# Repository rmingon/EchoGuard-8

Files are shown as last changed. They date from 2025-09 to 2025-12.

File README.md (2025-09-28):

# GPS Fusion Array with STM32F103

This repository contains the full design files, schematics, and firmware for a **GPS Fusion Array**:
a custom PCB with **8 ATGM336H GNSS modules** and an **STM32F103 MCU** that collects data from all receivers,
performs **real-time fusion**, and outputs the combined solution over **SPI**.

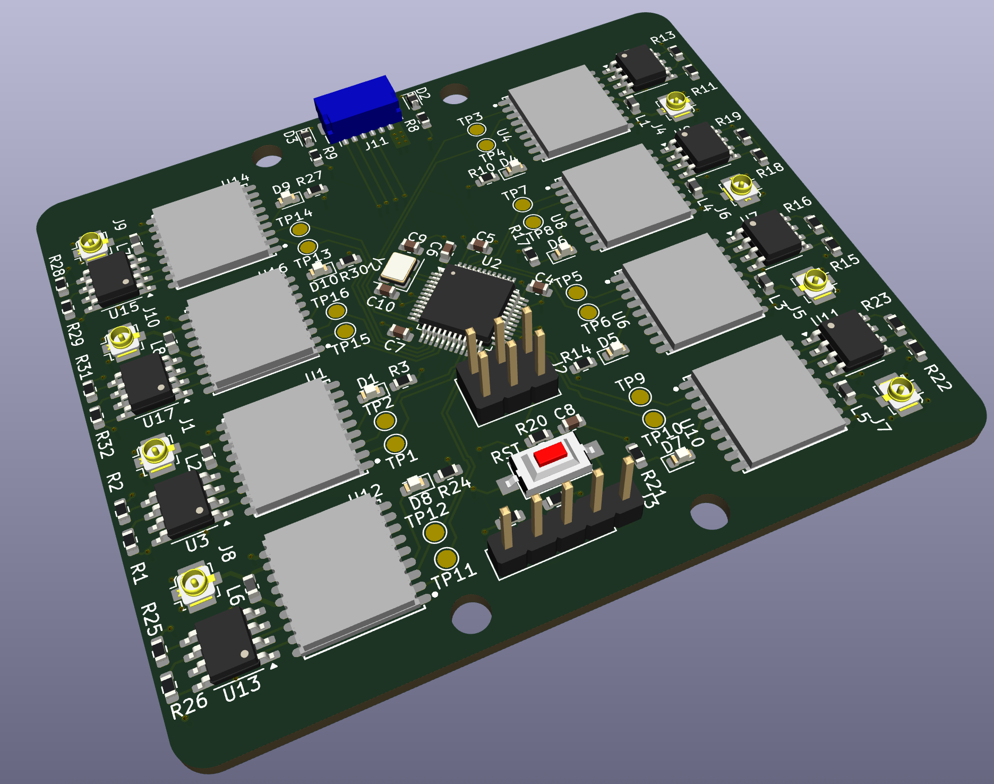
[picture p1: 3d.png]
3d


## Support on falconEdge

[FalconEdge repository](https://github.com/rmingon/Falcon-Edge)

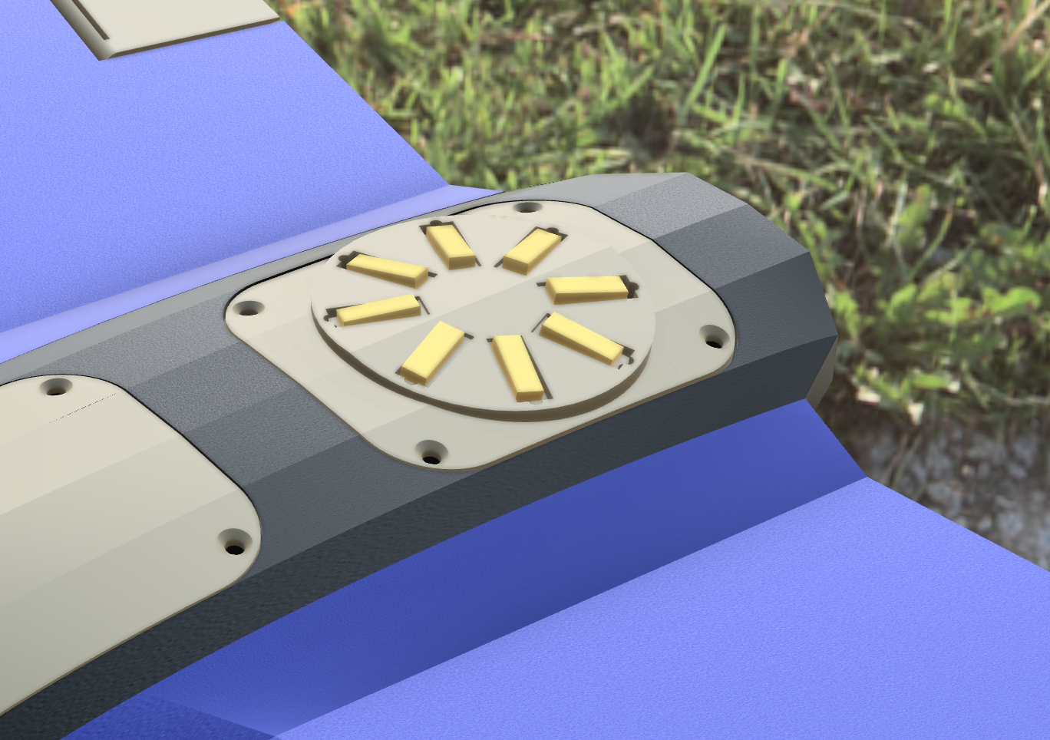
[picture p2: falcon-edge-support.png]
falconEdge_support


---

## Project Overview

| PCB Layout | Schematic | 3D View |
| --- | --- | --- |
| pcb.png | schematic.png | 3d.png  |

---

## Key Features

- **8× ATGM336H GPS modules** for redundant positioning
- **STM32F103** microcontroller for acquisition and fusion
- **SPI output interface** for fast integration with a master controller
- **Per-module power filtering** and **careful ground plane partitioning** to reduce RF interference
- **Compact, mountable PCB** with 3.3 V power input

---

## Why an Array of GPS Modules?

Traditional single-GPS solutions suffer from multipath, interference, and occasional dropouts.
Using 8 GPS modules in parallel offers:

- **Redundancy:** Even if one receiver loses lock, others keep tracking.
- **Noise Reduction:** Position noise is reduced by averaging multiple solutions.
- **Outlier Rejection:** Bad data can be discarded automatically.
- **Improved Accuracy:** Fusion of multiple measurements yields a more stable, reliable solution.

---

## RF & Interference Mitigation

This PCB design includes several techniques to minimize interference and maintain clean GNSS reception:

- **Dedicated RF Ground Plane:** Each GPS module has local ground pour to reduce mutual coupling.
- **Power Filtering:** Each module’s VCC line is decoupled with LC filters for low-noise operation.
- **Symmetric Layout:** GPS modules are evenly distributed to reduce antenna detuning.
- **Isolated Digital Section:** MCU and SPI routing are kept away from RF traces to reduce emissions.

---

## Data Fusion Algorithm

The STM32F103 runs a lightweight fusion algorithm:

- **NMEA Parsing** from all modules
- **Timestamp Synchronization** for simultaneous position updates
- **Weighted Average & Kalman Filtering** using HDOP as weight
- **Fault Detection:** Rejects outliers and maintains smooth position tracking

---

## Firmware

Features:

- **Complete NMEA Parsing** Supports GGA, RMC, GSA, GSV, VTG, and GLL sentences
- **Interrupt Support** Optional interrupt-driven data reception
- **Comprehensive Data** Position, time, satellites, signal quality, movement data
- **Signal Quality Analysis** SNR monitoring and satellite constellation health

---

## ATGM336H Technical Summary

| Parameter | Specification |
| --- | --- |
| Constellations | GPS, BeiDou, GLONASS, QZSS, SBAS |
| Positioning Accuracy | ~2.5 m CEP |
| Cold Start | < 35 s |
| Hot Start | < 1 s |
| Update Rate | Up to 10 Hz |
| Supply Voltage | 2.8 – 4.3 V |
| Interface | UART (NMEA) |
| Tracking Current | ~26 mA |
| Operating Temp | -40 °C to +85 °C |

---

## Hardware Details

- **MCU:** STM32F103C8T6
- **GPS:** 8× ATGM336H modules
- **I/O:** SPI slave output, UARTs for module communication
- **Power:** Single 3.3 V input, on-board filtering
- **Board:** 4-layer PCB, optimized RF layout

---

## Repository Structure

```
/hardware       # KiCad project files, schematics, PCB layout
/firmware       # STM32 source code for GPS fusion and SPI output
/docs           # Project documentation, images, diagrams
```

---

## Getting Started

1. **Assemble the PCB** and mount the GPS modules and STM32.
2. **Flash the firmware** using ST-Link.
3. **Connect SPI** to your master controller (e.g., Raspberry Pi or another STM32).
4. **Power the board** with 3.3 V regulated input.
5. **Start reading fused GPS data** from SPI.

## License

This project is licensed under the **CERN Open Hardware Licence Version 2**. See `LICENSE` file for full terms.

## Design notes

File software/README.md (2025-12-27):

# Software (PlatformIO)

This folder contains a minimal PlatformIO project targeting **STM32F103C8** using **STM32Cube (HAL)** + **FreeRTOS**.

## GNSS UART Pin Map

The hardware connects 8× ATGM336H modules using nets `TX_1..TX_8` / `RX_1..RX_8`:

- GNSS #1: TX=`PB10` (net `TX_1`), RX=`PB11` (net `RX_1`) → `USART3`
- GNSS #2: TX=`PA2` (net `TX_2`), RX=`PA3` (net `RX_2`) → `USART2`
- GNSS #3: TX=`PB6` (net `TX_3`), RX=`PB7` (net `RX_3`) → `USART1` (remapped)
- GNSS #4: TX=`PB8` (net `TX_4`), RX=`PB9` (net `RX_4`)
- GNSS #5: TX=`PB12` (net `TX_5`), RX=`PB13` (net `RX_5`)
- GNSS #6: TX=`PB14` (net `TX_6`), RX=`PB15` (net `RX_6`)
- GNSS #7: TX=`PA4` (net `TX_7`), RX=`PA5` (net `RX_7`)
- GNSS #8: TX=`PA6` (net `TX_8`), RX=`PA7` (net `RX_8`)

Only GNSS modules #1..#3 are on hardware USART pin pairs; the rest need a software UART (or other method) if all
8 modules must be received concurrently.

## SPI Fused Output (J11)

Hardware SPI connector `J11` (JST-SH 1x06):

- Pin 1: `SS` (PB1, active-low)
- Pin 2: `MOSI` (PB5)
- Pin 3: `MISO` (PB4)
- Pin 4: `SCK` (PB3)
- Pin 5: `GND`
- Pin 6: `+3.3V`

Firmware exposes the fused GNSS solution as an `SPI1` slave (remapped to PB3/PB4/PB5). Each `SS` assertion starts
a streamed `SPI_FUSION_PACKET_SIZE`-byte packet on `MISO` (see `include/spi_fusion.h`).

Packet (little-endian, `SPI_FUSION_PACKET_SIZE == 32`):

- `u32 magic` = `0x31464745` (`EGF1`)
- `u32 tick_ms`
- `i32 lat_e7`, `i32 lon_e7`, `i32 alt_cm`
- `u16 avg_hdop_centi`, `u16 max_residual_cm`
- `u8 status`, `u8 used_modules`, `u8 rejected_modules`, `u8 has_fix`
- `u16 crc16_ccitt` (over first 30 bytes)

## Build / Upload

- Install PlatformIO CLI (or use the VS Code PlatformIO extension).
- From `software/`:
  - Build: `pio run`
  - Upload (ST-Link): `pio run -t upload`

`FreeRTOS-Kernel` is pulled via `lib_deps` (requires network access on first build).

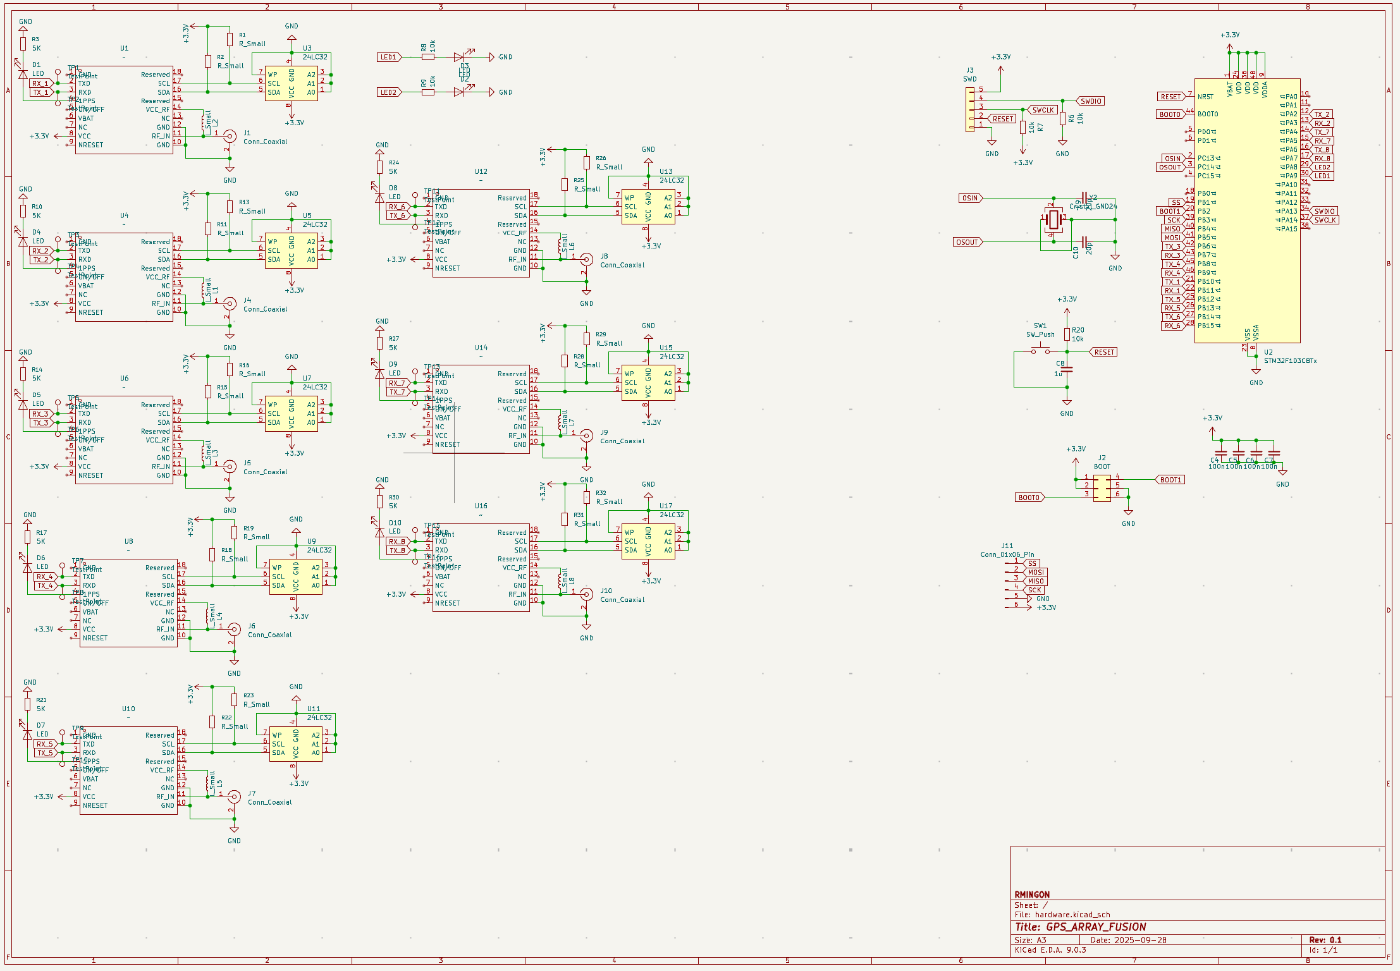
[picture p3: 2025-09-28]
schematic.png

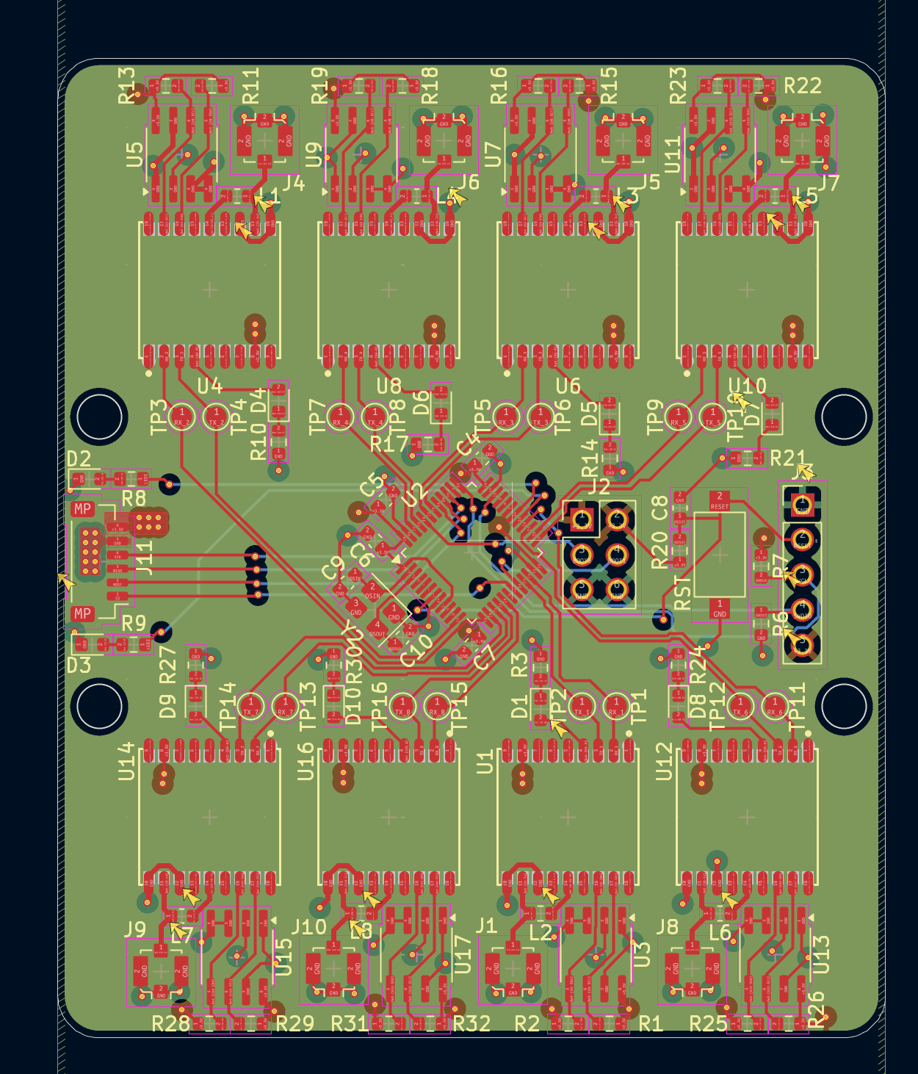
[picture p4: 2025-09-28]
pcb.png

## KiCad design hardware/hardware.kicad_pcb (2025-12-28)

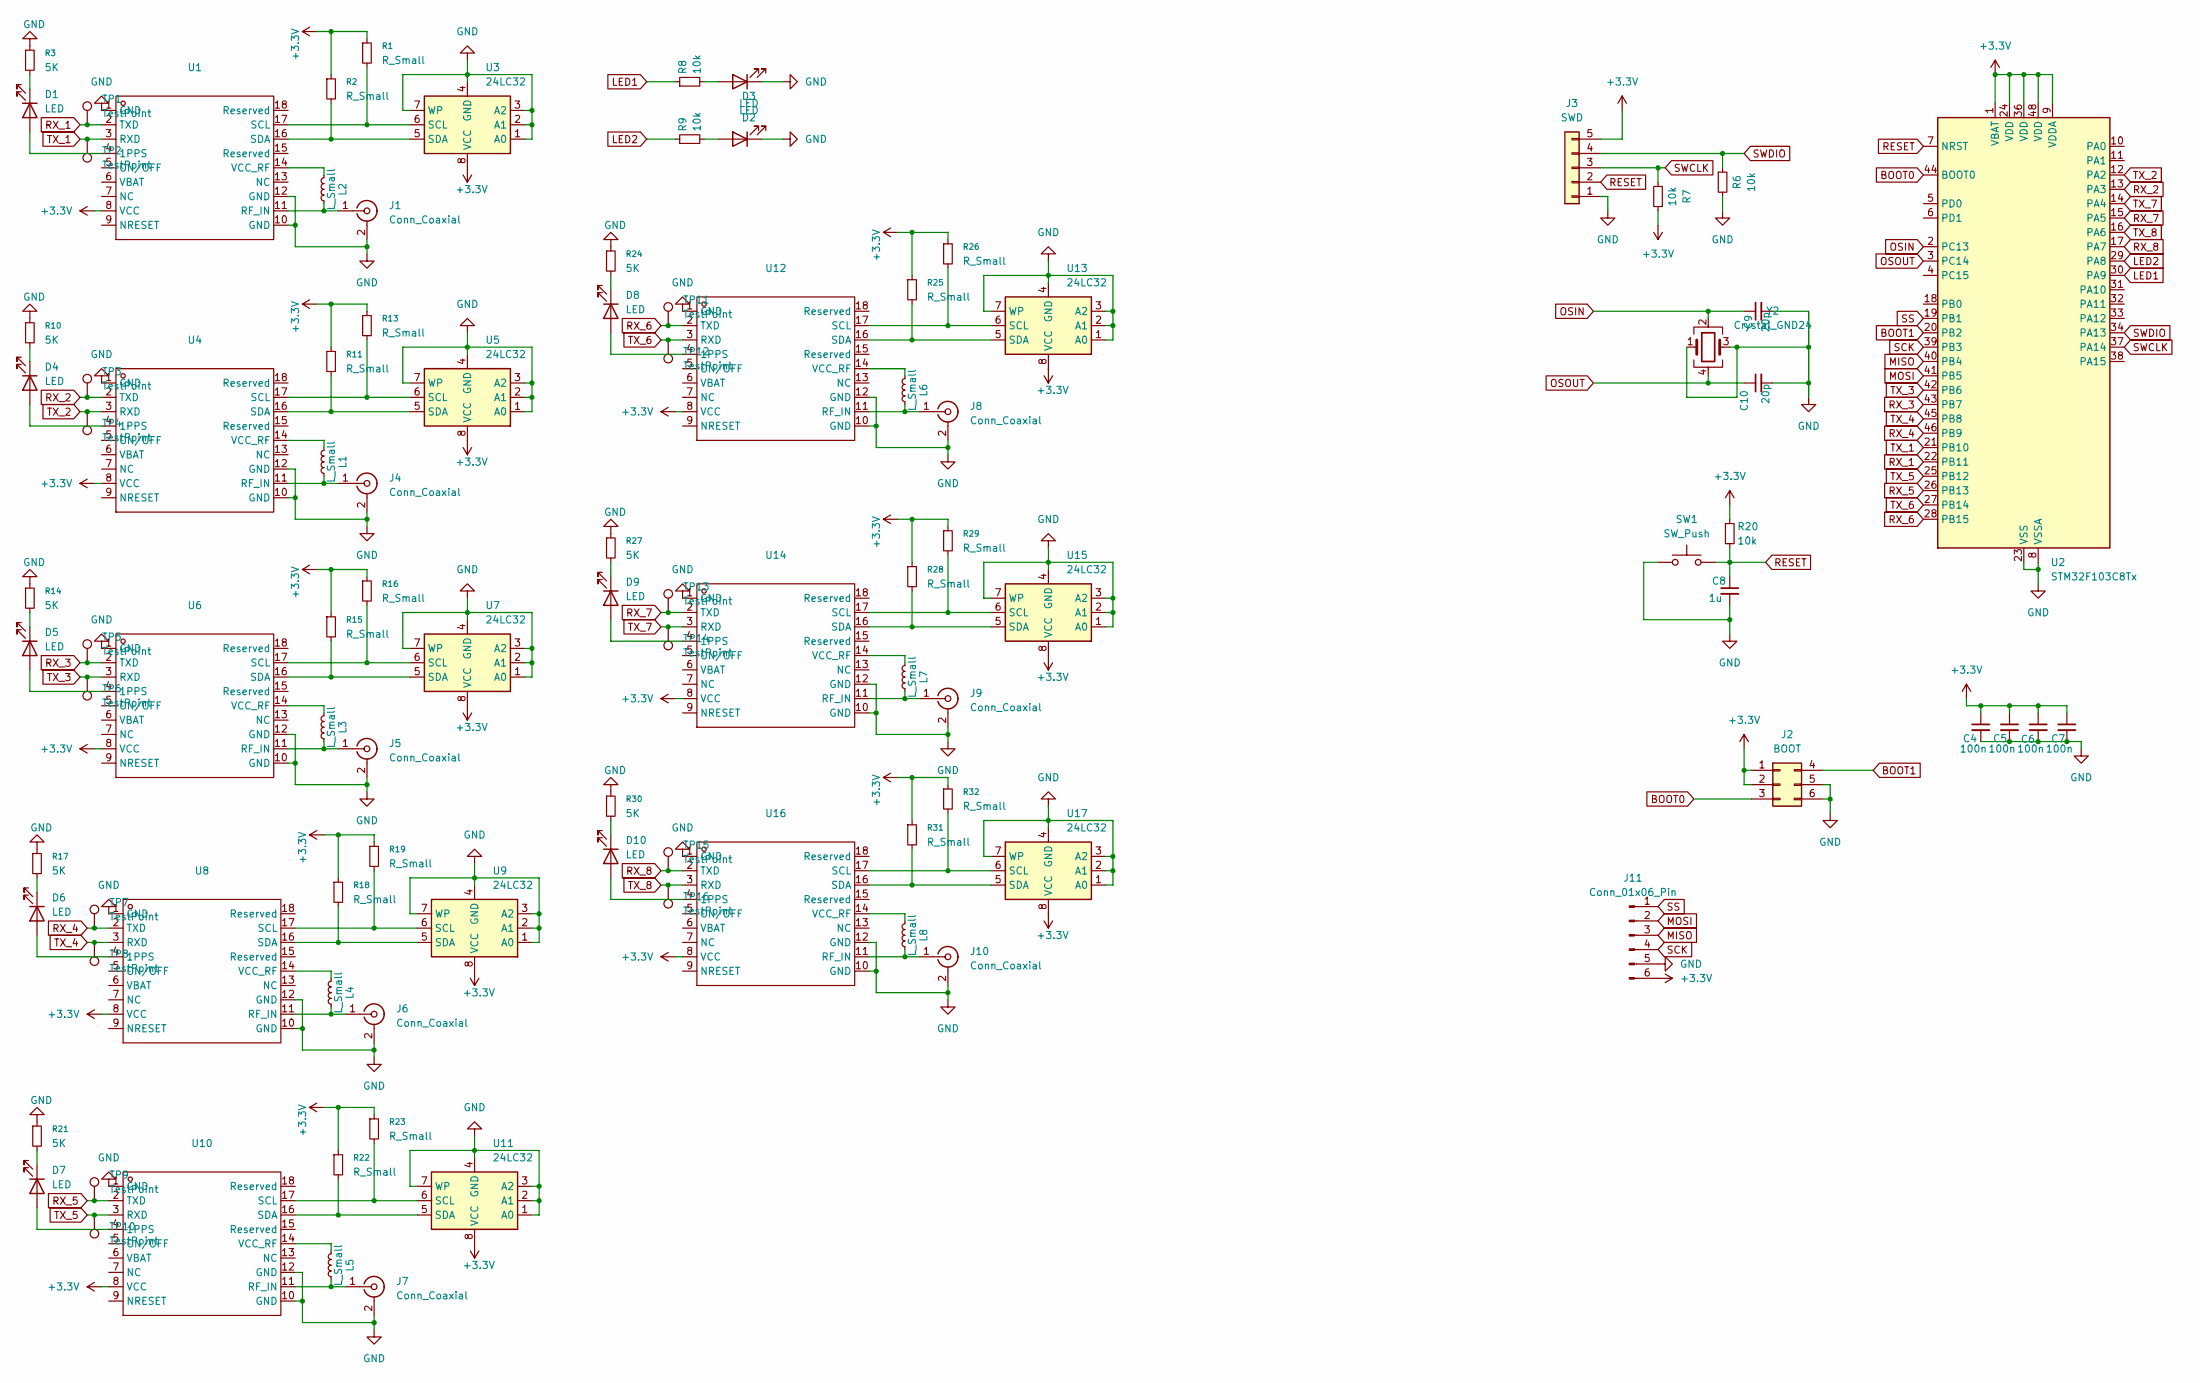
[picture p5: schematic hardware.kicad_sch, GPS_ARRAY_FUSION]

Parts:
C4, C5, C6, C7: 100n; C_0603_1608Metric
C8: 1u; C_0603_1608Metric
C9, C10: 20p; C_0603_1608Metric
D1, D4, D5, D6, D7, D8, D9, D10: LED; LED_0603_1608Metric
D2, D3: LED; D_0603_1608Metric
J1, J4, J5, J6, J7, J8, J9, J10: Conn_Coaxial; U.FL_Molex_MCRF_73412-0110_Vertical
J2: BOOT; PinHeader_2x03_P2.54mm_Vertical
J3: SWD; PinHeader_1x05_P2.54mm_Vertical
J11: Conn_01x06_Pin; JST_SH_BM06B-SRSS-TB_1x06-1MP_P1.00mm_Vertical
L1, L2, L3, L4, L5, L6, L7, L8: L_Small; L_0603_1608Metric
R1, R2, R11, R13, R15, R16, R18, R19, R22, R23, R25, R26, R28, R29, R31, R32: R_Small; R_0603_1608Metric
R3, R10, R14, R17, R21, R24, R27, R30: 5K; R_0603_1608Metric
R6, R7, R8, R9, R20: 10k; R_0603_1608Metric
SW1: SW_Push; SW_SPST_CK_RS282G05A3
TP1, TP2, TP3, TP4, TP5, TP6, TP7, TP8, TP9, TP10, TP11, TP12, TP13, TP14, TP15, TP16: TestPoint; TestPoint_Pad_D1.5mm
U1, U4, U6, U8, U10, U12, U14, U16: GPSM-SMD_ATGM336H-TR; Manufacturer Part ATGM336H-5N31; LCSC Part Name BDS/GNSS 全星座定位导航模块
U2: STM32F103C8Tx; LQFP-48_7x7mm_P0.5mm
U3, U5, U7, U9, U11, U13, U15, U17: 24LC32; SOIC-8_3.9x4.9mm_P1.27mm
Y2: Crystal_GND24; Crystal_SMD_3225-4Pin_3.2x2.5mm

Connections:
+3.3V: C4.1, C5.1, C6.1, C7.1, J2.1, J2.2, J3.5, J11.6, R1.1, R2.1, R7.1, R11.1, R13.1, R15.1, R16.1, R18.1, R19.1, R20.1, R22.1, R23.1, R25.1, R26.1, R28.1, R29.1, R31.1, R32.1, U1.8 (VCC), U2.1 (VBAT), U2.9 (VDDA), U2.24 (VDD), U2.36 (VDD), U2.48 (VDD), U3.8 (VCC), U4.8 (VCC), U5.8 (VCC), U6.8 (VCC), U7.8 (VCC), U8.8 (VCC), U9.8 (VCC), U10.8 (VCC), U11.8 (VCC), U12.8 (VCC), U13.8 (VCC), U14.8 (VCC), U15.8 (VCC), U16.8 (VCC), U17.8 (VCC)
BOOT0: J2.3, U2.44 (BOOT0)
BOOT1: J2.4, U2.20 (PB2)
GND: C4.2, C5.2, C6.2, C7.2, C8.2, C9.2, C10.2, D2.1 (K), D3.1 (K), J1.2 (Ext), J2.5, J2.6, J3.1, J4.2 (Ext), J5.2 (Ext), J6.2 (Ext), J7.2 (Ext), J8.2 (Ext), J9.2 (Ext), J10.2 (Ext), J11.5, R3.1, R6.2, R10.1, R14.1, R17.1, R21.1, R24.1, R27.1, R30.1, SW1.1, U1.1 (GND), U1.10 (GND), U1.12 (GND), U2.8 (VSSA), U2.23 (VSS), U2.35 (VSS), U2.47 (VSS), U3.1 (A0), U3.2 (A1), U3.3 (A2), U3.4 (GND), U3.7 (WP), U4.1 (GND), U4.10 (GND), U4.12 (GND), U5.1 (A0), U5.2 (A1), U5.3 (A2), U5.4 (GND), U5.7 (WP), U6.1 (GND), U6.10 (GND), U6.12 (GND), U7.1 (A0), U7.2 (A1), U7.3 (A2), U7.4 (GND), U7.7 (WP), U8.1 (GND), U8.10 (GND), U8.12 (GND), U9.1 (A0), U9.2 (A1), U9.3 (A2), U9.4 (GND), U9.7 (WP), U10.1 (GND), U10.10 (GND), U10.12 (GND), U11.1 (A0), U11.2 (A1), U11.3 (A2), U11.4 (GND), U11.7 (WP), U12.1 (GND), U12.10 (GND), U12.12 (GND), U13.1 (A0), U13.2 (A1), U13.3 (A2), U13.4 (GND), U13.7 (WP), U14.1 (GND), U14.10 (GND), U14.12 (GND), U15.1 (A0), U15.2 (A1), U15.3 (A2), U15.4 (GND), U15.7 (WP), U16.1 (GND), U16.10 (GND), U16.12 (GND), U17.1 (A0), U17.2 (A1), U17.3 (A2), U17.4 (GND), U17.7 (WP), Y2.1, Y2.3
LED1: R8.1, U2.30 (PA9)
LED2: R9.1, U2.29 (PA8)
MISO: J11.3, U2.40 (PB4)
MOSI: J11.2, U2.41 (PB5)
unnamed: D1.2 (A), U1.4 (1PPS)
unnamed: D1.1 (K), R3.2
unnamed: D2.2 (A), R8.2
unnamed: D3.2 (A), R9.2
unnamed: D4.2 (A), U4.4 (1PPS)
unnamed: D4.1 (K), R10.2
unnamed: D5.2 (A), U6.4 (1PPS)
unnamed: D5.1 (K), R14.2
unnamed: D6.2 (A), U8.4 (1PPS)
unnamed: D6.1 (K), R17.2
unnamed: D7.2 (A), U10.4 (1PPS)
unnamed: D7.1 (K), R21.2
unnamed: D8.2 (A), U12.4 (1PPS)
unnamed: D8.1 (K), R24.2
unnamed: D9.2 (A), U14.4 (1PPS)
unnamed: D9.1 (K), R27.2
unnamed: D10.2 (A), U16.4 (1PPS)
unnamed: D10.1 (K), R30.2
unnamed: J1.1 (In), L2.1, U1.11 (RF_IN)
unnamed: J4.1 (In), L1.1, U4.11 (RF_IN)
unnamed: J5.1 (In), L3.1, U6.11 (RF_IN)
unnamed: J6.1 (In), L4.1, U8.11 (RF_IN)
unnamed: J7.1 (In), L5.1, U10.11 (RF_IN)
unnamed: J8.1 (In), L6.1, U12.11 (RF_IN)
unnamed: J9.1 (In), L7.1, U14.11 (RF_IN)
unnamed: J10.1 (In), L8.1, U16.11 (RF_IN)
unnamed: R1.2, U1.17 (SCL), U3.6 (SCL)
unnamed: R2.2, U1.16 (SDA), U3.5 (SDA)
unnamed: L2.2, U1.14 (VCC_RF)
unnamed: R13.2, U4.17 (SCL), U5.6 (SCL)
unnamed: R11.2, U4.16 (SDA), U5.5 (SDA)
unnamed: L1.2, U4.14 (VCC_RF)
unnamed: R16.2, U6.17 (SCL), U7.6 (SCL)
unnamed: R15.2, U6.16 (SDA), U7.5 (SDA)
unnamed: L3.2, U6.14 (VCC_RF)
unnamed: R19.2, U8.17 (SCL), U9.6 (SCL)
unnamed: R18.2, U8.16 (SDA), U9.5 (SDA)
unnamed: L4.2, U8.14 (VCC_RF)
unnamed: R23.2, U10.17 (SCL), U11.6 (SCL)
unnamed: R22.2, U10.16 (SDA), U11.5 (SDA)
unnamed: L5.2, U10.14 (VCC_RF)
unnamed: R26.2, U12.17 (SCL), U13.6 (SCL)
unnamed: R25.2, U12.16 (SDA), U13.5 (SDA)
unnamed: L6.2, U12.14 (VCC_RF)
unnamed: R29.2, U14.17 (SCL), U15.6 (SCL)
unnamed: R28.2, U14.16 (SDA), U15.5 (SDA)
unnamed: L7.2, U14.14 (VCC_RF)
unnamed: R32.2, U16.17 (SCL), U17.6 (SCL)
unnamed: R31.2, U16.16 (SDA), U17.5 (SDA)
unnamed: L8.2, U16.14 (VCC_RF)
OSIN: C9.1, U2.2 (PC13), Y2.2
OSOUT: C10.1, U2.3 (PC14), Y2.4
RESET: C8.1, J3.2, R20.2, SW1.2, U2.7 (NRST)
RX_1: TP1.1, U1.2 (TXD), U2.22 (PB11)
RX_2: TP3.1, U2.13 (PA3), U4.2 (TXD)
RX_3: TP5.1, U2.43 (PB7), U6.2 (TXD)
RX_4: TP7.1, U2.46 (PB9), U8.2 (TXD)
RX_5: TP9.1, U2.26 (PB13), U10.2 (TXD)
RX_6: TP11.1, U2.28 (PB15), U12.2 (TXD)
RX_7: TP13.1, U2.15 (PA5), U14.2 (TXD)
RX_8: TP15.1, U2.17 (PA7), U16.2 (TXD)
SCK: J11.4, U2.39 (PB3)
SS: J11.1, U2.19 (PB1)
SWCLK: J3.3, R7.2, U2.37 (PA14)
SWDIO: J3.4, R6.1, U2.34 (PA13)
TX_1: TP2.1, U1.3 (RXD), U2.21 (PB10)
TX_2: TP4.1, U2.12 (PA2), U4.3 (RXD)
TX_3: TP6.1, U2.42 (PB6), U6.3 (RXD)
TX_4: TP8.1, U2.45 (PB8), U8.3 (RXD)
TX_5: TP10.1, U2.25 (PB12), U10.3 (RXD)
TX_6: TP12.1, U2.27 (PB14), U12.3 (RXD)
TX_7: TP14.1, U2.14 (PA4), U14.3 (RXD)
TX_8: TP16.1, U2.16 (PA6), U16.3 (RXD)

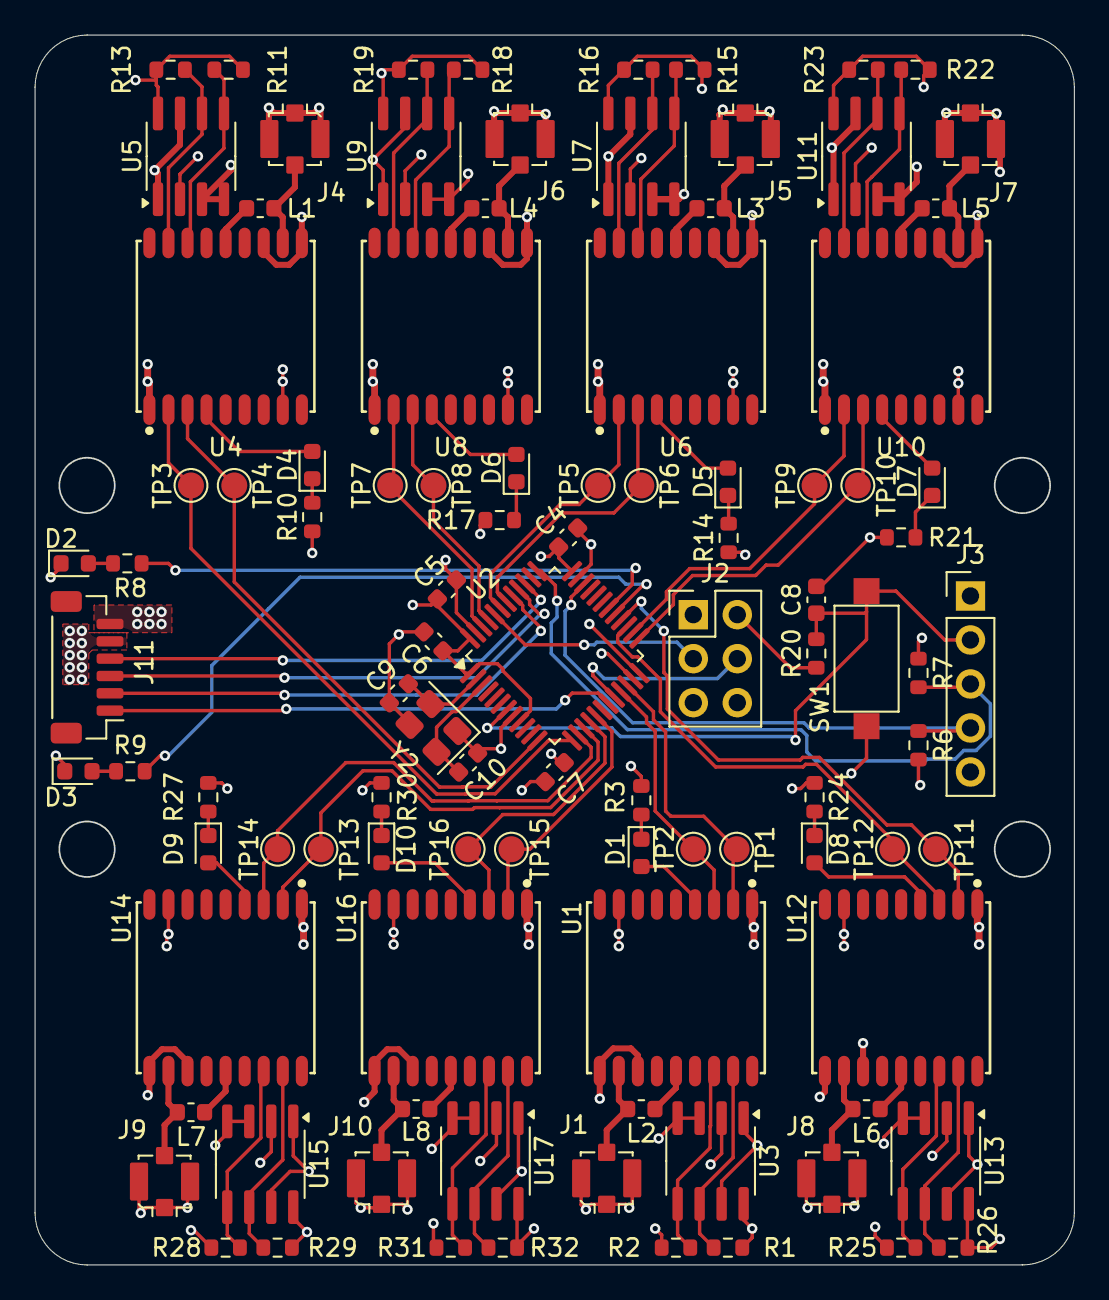
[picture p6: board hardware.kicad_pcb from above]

Board: 4 copper layers, 60.0 x 71.0 mm, 100 parts (0 on the bottom side), 81 nets.

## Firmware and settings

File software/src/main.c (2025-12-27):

#include "stm32f1xx_hal.h"

#include "FreeRTOS.h"
#include "task.h"

#include <stdio.h>

#include "gnss.h"
#include "gnss_fusion.h"
#include "gnss_uart.h"
#include "spi_fusion.h"

static void SystemClock_Config(void);
static void MX_GPIO_Init(void);

extern void vPortSVCHandler(void);
extern void xPortPendSVHandler(void);
extern void xPortSysTickHandler(void);

static void LedTask(void *argument)
{
	(void)argument;
	while (1)
	{
		HAL_GPIO_TogglePin(GPIOA, GPIO_PIN_8);
		vTaskDelay(pdMS_TO_TICKS(250));
	}
}

static const char *FusionStatusToString(GnssFusionStatus status)
{
	switch (status)
	{
	case GNSS_FUSION_NO_FIX:
		return "NO_FIX";
	case GNSS_FUSION_OK:
		return "OK";
	case GNSS_FUSION_DEGRADED:
		return "DEGRADED";
	case GNSS_FUSION_INTERFERENCE:
		return "INTERFERENCE";
	default:
		return "?";
	}
}

static void PrintCoordE7(const char *name, int32_t value_e7)
{
	int64_t v = (int64_t)value_e7;
	char sign = '+';
	if (v < 0)
	{
		sign = '-';
		v = -v;
	}

	int32_t deg = (int32_t)(v / 10000000);
	int32_t frac = (int32_t)(v % 10000000);
	printf("%s=%c%ld.%07ld", name, sign, (long)deg, (long)frac);
}

static void FusionPrintTask(void *argument)
{
	(void)argument;
	while (1)
	{
		GnssFusionResult r = {0};
		if (GnssFusion_GetResult(&r) && r.has_fix)
		{
			printf("[fusion %s used=%u rej=%u hdop=%u res=%ucm] ",
			       FusionStatusToString(r.status),
			       (unsigned)r.used_modules,
			       (unsigned)r.rejected_modules,
			       (unsigned)r.avg_hdop_centi,
			       (unsigned)r.max_residual_cm);
			PrintCoordE7("lat", r.lat_e7);
			printf(" ");
			PrintCoordE7("lon", r.lon_e7);
			printf(" alt=%.2fm tick=%lu\r\n", (double)r.alt_cm / 100.0, (unsigned long)r.last_update_tick);
		}
		else
		{
			printf("[fusion %s] no fix\r\n", FusionStatusToString(r.status));
		}

		vTaskDelay(pdMS_TO_TICKS(1000));
	}
}

void SVC_Handler(void)
{
	vPortSVCHandler();
}

void PendSV_Handler(void)
{
	xPortPendSVHandler();
}

void SysTick_Handler(void)
{
	HAL_IncTick();
	xPortSysTickHandler();
}

void USART1_IRQHandler(void)
{
	GnssUart_IrqHandler(USART1);
}

void USART2_IRQHandler(void)
{
	GnssUart_IrqHandler(USART2);
}

void USART3_IRQHandler(void)
{
	GnssUart_IrqHandler(USART3);
}

void SPI1_IRQHandler(void)
{
	SpiFusion_SpiIrqHandler();
}

void EXTI1_IRQHandler(void)
{
	HAL_GPIO_EXTI_IRQHandler(GPIO_PIN_1);
}

void TIM2_IRQHandler(void)
{
	GnssUart_TimIrqHandler();
}

int main(void)
{
	HAL_Init();
	SystemClock_Config();
	MX_GPIO_Init();

	Gnss_Init(9600);
	GnssFusion_Init();
	SpiFusion_Init();

	xTaskCreate(Gnss_Task, "gnss", 256, NULL, tskIDLE_PRIORITY + 2, NULL);
	xTaskCreate(GnssFusion_Task, "fusion", 256, NULL, tskIDLE_PRIORITY + 2, NULL);
	xTaskCreate(FusionPrintTask, "print", 256, NULL, tskIDLE_PRIORITY + 1, NULL);
	xTaskCreate(LedTask, "led", 128, NULL, tskIDLE_PRIORITY + 1, NULL);
	vTaskStartScheduler();

	while (1)
	{
	}
}

static void SystemClock_Config(void)
{
	RCC_OscInitTypeDef oscillator_config = {0};
	RCC_ClkInitTypeDef clock_config = {0};

	/* Typical BluePill: 8MHz HSE -> 72MHz SYSCLK. */
	oscillator_config.OscillatorType = RCC_OSCILLATORTYPE_HSE;
	oscillator_config.HSEState = RCC_HSE_ON;
	oscillator_config.HSEPredivValue = RCC_HSE_PREDIV_DIV1;
	oscillator_config.PLL.PLLState = RCC_PLL_ON;
	oscillator_config.PLL.PLLSource = RCC_PLLSOURCE_HSE;
	oscillator_config.PLL.PLLMUL = RCC_PLL_MUL9;
	if (HAL_RCC_OscConfig(&oscillator_config) != HAL_OK)
	{
		while (1)
		{
		}
	}

	clock_config.ClockType =
		RCC_CLOCKTYPE_SYSCLK | RCC_CLOCKTYPE_HCLK | RCC_CLOCKTYPE_PCLK1 | RCC_CLOCKTYPE_PCLK2;
	clock_config.SYSCLKSource = RCC_SYSCLKSOURCE_PLLCLK;
	clock_config.AHBCLKDivider = RCC_SYSCLK_DIV1;
	clock_config.APB1CLKDivider = RCC_HCLK_DIV2;
	clock_config.APB2CLKDivider = RCC_HCLK_DIV1;

	if (HAL_RCC_ClockConfig(&clock_config, FLASH_LATENCY_2) != HAL_OK)
	{
		while (1)
		{
		}
	}
}

static void MX_GPIO_Init(void)
{
	__HAL_RCC_GPIOA_CLK_ENABLE();

	GPIO_InitTypeDef gpio = {0};
	gpio.Pin = GPIO_PIN_8;
	gpio.Mode = GPIO_MODE_OUTPUT_PP;
	gpio.Pull = GPIO_NOPULL;
	gpio.Speed = GPIO_SPEED_FREQ_LOW;
	HAL_GPIO_Init(GPIOA, &gpio);

	HAL_GPIO_WritePin(GPIOA, GPIO_PIN_8, GPIO_PIN_SET);
}

void vApplicationMallocFailedHook(void)
{
	taskDISABLE_INTERRUPTS();
	while (1)
	{
	}
}

void vApplicationStackOverflowHook(TaskHandle_t task, char *task_name)
{
	(void)task;
	(void)task_name;
	taskDISABLE_INTERRUPTS();
	while (1)
	{
	}
}

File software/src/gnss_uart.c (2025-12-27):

#include "gnss_uart.h"

#include <stdbool.h>
#include <stddef.h>
#include <string.h>

static UART_HandleTypeDef huart1;
static UART_HandleTypeDef huart2;
static UART_HandleTypeDef huart3;

#ifndef GNSS_UART_RING_SIZE
#define GNSS_UART_RING_SIZE 256u
#endif

typedef struct {
	volatile uint16_t head;
	volatile uint16_t tail;
	uint8_t buffer[GNSS_UART_RING_SIZE];
} RingBuffer;

static RingBuffer rb_usart1;
static RingBuffer rb_usart2;
static RingBuffer rb_usart3;

typedef enum {
	SOFT_RX_IDLE = 0,
	SOFT_RX_START = 1,
	SOFT_RX_DATA = 2,
	SOFT_RX_STOP = 3,
} SoftRxState;

typedef struct {
	SoftRxState state;
	uint8_t sub_tick;
	uint8_t bit_index;
	uint8_t byte;
	RingBuffer rb;
} SoftUartChannel;

static SoftUartChannel soft_channels[GNSS_MODULE_COUNT];

static uint8_t rx_byte_usart1;
static uint8_t rx_byte_usart2;
static uint8_t rx_byte_usart3;

const GnssUartPins kGnssUartPins[GNSS_MODULE_COUNT] = {
	{.module_index = 1,
	 .tx_port = GPIOB,
	 .tx_pin = GPIO_PIN_10,
	 .rx_port = GPIOB,
	 .rx_pin = GPIO_PIN_11,
	 .uart_instance = USART3},
	{.module_index = 2,
	 .tx_port = GPIOA,
	 .tx_pin = GPIO_PIN_2,
	 .rx_port = GPIOA,
	 .rx_pin = GPIO_PIN_3,
	 .uart_instance = USART2},
	{.module_index = 3,
	 .tx_port = GPIOB,
	 .tx_pin = GPIO_PIN_6,
	 .rx_port = GPIOB,
	 .rx_pin = GPIO_PIN_7,
	 .uart_instance = USART1},
	{.module_index = 4,
	 .tx_port = GPIOB,
	 .tx_pin = GPIO_PIN_8,
	 .rx_port = GPIOB,
	 .rx_pin = GPIO_PIN_9,
	 .uart_instance = NULL},
	{.module_index = 5,
	 .tx_port = GPIOB,
	 .tx_pin = GPIO_PIN_12,
	 .rx_port = GPIOB,
	 .rx_pin = GPIO_PIN_13,
	 .uart_instance = NULL},
	{.module_index = 6,
	 .tx_port = GPIOB,
	 .tx_pin = GPIO_PIN_14,
	 .rx_port = GPIOB,
	 .rx_pin = GPIO_PIN_15,
	 .uart_instance = NULL},
	{.module_index = 7,
	 .tx_port = GPIOA,
	 .tx_pin = GPIO_PIN_4,
	 .rx_port = GPIOA,
	 .rx_pin = GPIO_PIN_5,
	 .uart_instance = NULL},
	{.module_index = 8,
	 .tx_port = GPIOA,
	 .tx_pin = GPIO_PIN_6,
	 .rx_port = GPIOA,
	 .rx_pin = GPIO_PIN_7,
	 .uart_instance = NULL},
};

static UART_HandleTypeDef *hardware_handle_for_instance(USART_TypeDef *instance) {
	if (instance == USART1) {
		return &huart1;
	}
	if (instance == USART2) {
		return &huart2;
	}
	if (instance == USART3) {
		return &huart3;
	}
	return NULL;
}

static RingBuffer *ring_for_instance(USART_TypeDef *instance) {
	if (instance == USART1) {
		return &rb_usart1;
	}
	if (instance == USART2) {
		return &rb_usart2;
	}
	if (instance == USART3) {
		return &rb_usart3;
	}
	return NULL;
}

static uint8_t *rx_byte_for_instance(USART_TypeDef *instance) {
	if (instance == USART1) {
		return &rx_byte_usart1;
	}
	if (instance == USART2) {
		return &rx_byte_usart2;
	}
	if (instance == USART3) {
		return &rx_byte_usart3;
	}
	return NULL;
}

UART_HandleTypeDef *GnssUart_GetHardwareHandle(uint8_t module_index) {
	for (size_t i = 0; i < GNSS_MODULE_COUNT; i++) {
		if (kGnssUartPins[i].module_index == module_index) {
			return hardware_handle_for_instance(kGnssUartPins[i].uart_instance);
		}
	}
	return NULL;
}

void GnssUart_GpioInit(void) {
	__HAL_RCC_AFIO_CLK_ENABLE();
	__HAL_RCC_GPIOA_CLK_ENABLE();
	__HAL_RCC_GPIOB_CLK_ENABLE();

	/* GNSS #3 uses USART1 remapped to PB6/PB7. */
	__HAL_AFIO_REMAP_USART1_ENABLE();

	for (size_t i = 0; i < GNSS_MODULE_COUNT; i++) {
		const GnssUartPins *pins = &kGnssUartPins[i];

		GPIO_InitTypeDef gpio = {0};

		/* RX: input (works for both HW UART and future SW UART). */
		gpio.Pin = pins->rx_pin;
		gpio.Mode = GPIO_MODE_INPUT;
		gpio.Pull = GPIO_NOPULL;
		HAL_GPIO_Init(pins->rx_port, &gpio);

		/* TX: HW UART uses alternate function; otherwise default to GPIO output. */
		gpio.Pin = pins->tx_pin;
		gpio.Pull = GPIO_NOPULL;
		gpio.Speed = GPIO_SPEED_FREQ_HIGH;
		gpio.Mode = (pins->uart_instance != NULL) ? GPIO_MODE_AF_PP : GPIO_MODE_INPUT;
		HAL_GPIO_Init(pins->tx_port, &gpio);
	}
}

static void uart_init(UART_HandleTypeDef *huart, USART_TypeDef *instance, uint32_t baudrate) {
	huart->Instance = instance;
	huart->Init.BaudRate = baudrate;
	huart->Init.WordLength = UART_WORDLENGTH_8B;
	huart->Init.StopBits = UART_STOPBITS_1;
	huart->Init.Parity = UART_PARITY_NONE;
	huart->Init.Mode = UART_MODE_TX_RX;
	huart->Init.HwFlowCtl = UART_HWCONTROL_NONE;
	huart->Init.OverSampling = UART_OVERSAMPLING_16;
	(void)HAL_UART_Init(huart);
}

void GnssUart_HardwareUartsInit(uint32_t baudrate) {
	__HAL_RCC_USART1_CLK_ENABLE();
	__HAL_RCC_USART2_CLK_ENABLE();
	__HAL_RCC_USART3_CLK_ENABLE();

	/*
	 * Note: only GNSS modules #1..#3 are wired to valid STM32F103 hardware USART pin pairs:
	 * - #1: USART3 (PB10/PB11)
	 * - #2: USART2 (PA2/PA3)
	 * - #3: USART1 remap (PB6/PB7)
	 *
	 * Modules #4..#8 require a software UART (or other acquisition method) if you intend to
	 * receive from all 8 modules concurrently.
	 */
	uart_init(&huart1, USART1, baudrate);
	uart_init(&huart2, USART2, baudrate);
	uart_init(&huart3, USART3, baudrate);

	HAL_NVIC_SetPriority(USART1_IRQn, 6, 0);
	HAL_NVIC_EnableIRQ(USART1_IRQn);
	HAL_NVIC_SetPriority(USART2_IRQn, 6, 0);
	HAL_NVIC_EnableIRQ(USART2_IRQn);
	HAL_NVIC_SetPriority(USART3_IRQn, 6, 0);
	HAL_NVIC_EnableIRQ(USART3_IRQn);
}

void GnssUart_StartHardwareRx(void) {
	(void)HAL_UART_Receive_IT(&huart1, &rx_byte_usart1, 1);
	(void)HAL_UART_Receive_IT(&huart2, &rx_byte_usart2, 1);
	(void)HAL_UART_Receive_IT(&huart3, &rx_byte_usart3, 1);
}

static void ring_push_byte(RingBuffer *rb, uint8_t byte) {
	uint16_t head = rb->head;
	uint16_t next = (uint16_t)((head + 1u) % (uint16_t)sizeof(rb->buffer));
	if (next == rb->tail) {
		return;
	}
	rb->buffer[head] = byte;
	rb->head = next;
}

static size_t ring_pop_bytes(RingBuffer *rb, uint8_t *dst, size_t max_len) {
	size_t count = 0;
	while (count < max_len) {
		uint16_t tail = rb->tail;
		if (tail == rb->head) {
			break;
		}
		dst[count++] = rb->buffer[tail];
		rb->tail = (uint16_t)((tail + 1u) % (uint16_t)sizeof(rb->buffer));
	}
	return count;
}

size_t GnssUart_ReadBytes(uint8_t module_index, uint8_t *dst, size_t max_len) {
	UART_HandleTypeDef *huart = GnssUart_GetHardwareHandle(module_index);
	if (huart != NULL && huart->Instance != NULL) {
		RingBuffer *rb = ring_for_instance(huart->Instance);
		if (rb == NULL) {
			return 0;
		}
		return ring_pop_bytes(rb, dst, max_len);
	}

	if (module_index < 1 || module_index > GNSS_MODULE_COUNT) {
		return 0;
	}
	return ring_pop_bytes(&soft_channels[module_index - 1].rb, dst, max_len);
}

void GnssUart_IrqHandler(USART_TypeDef *instance) {
	UART_HandleTypeDef *huart = hardware_handle_for_instance(instance);
	if (huart == NULL) {
		return;
	}
	HAL_UART_IRQHandler(huart);
}

void HAL_UART_RxCpltCallback(UART_HandleTypeDef *huart) {
	if (huart == NULL || huart->Instance == NULL) {
		return;
	}
	RingBuffer *rb = ring_for_instance(huart->Instance);
	uint8_t *byte = rx_byte_for_instance(huart->Instance);
	if (rb == NULL || byte == NULL) {
		return;
	}
	ring_push_byte(rb, *byte);
	(void)HAL_UART_Receive_IT(huart, byte, 1);
}
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

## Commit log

2025-09-27 add first gps footprint
    [hardware.kicad_pcb, hardware.kicad_sch]
2025-09-27 first wiring GPS with LNA
    [hardware.kicad_sch]
2025-09-27 place all components on pcb
    [hardware.kicad_pcb, hardware.kicad_sch]
2025-09-27 add power and comm connector
    [hardware.kicad_pcb, hardware.kicad_sch]
2025-09-28 full wiring pcb
    [hardware.kicad_pcb, hardware.kicad_sch]
2025-09-28 add connector step
    [hardware.kicad_pcb, hardware.kicad_sch]
2025-12-27 add minimal firmware uart control
2025-12-27 fix led pin
2025-12-27 add light fusion system + debug printing
2025-12-27 add spi slave system
2025-12-28 fix gnss ground module
    [hardware.kicad_pcb, hardware.kicad_sch]
2026-10-17 add GM capacitor + vbat to 3.3 + move osc on correct pins on stm32
